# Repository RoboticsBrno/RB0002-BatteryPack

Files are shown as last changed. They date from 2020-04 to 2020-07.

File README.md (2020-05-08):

# RB0002-BatteryPack

Universal 2 cells Li-Ion battery pack with separate USB charger PCB for robot
power supplying.

This battery pack is designed for continuous 8.4 V / 15 A.

View this project on [CADLAB.io](https://cadlab.io/project/22740/).

License: [CC BY-SA 4.0](https://creativecommons.org/licenses/by-sa/4.0/?)

## Repository Structure

- `batteryPack` contains the main schematics and board drawing
- `doc` contains CubeMX pinout of the MCU, resistor calculation spreadsheet,
  etc.
- `footprints` contains the board-specific footprints
- `symbols` contains the board-specific symbols
- `tools` contains few scripts for automatization

## Building

Simply call `make` in the top-top level directory. The `build` directory will
them contain:

- split boards for the charger and the battery pack
- zipped gerbers for the boards you can directly use for manufacturing

Makefile uses [KiKit](https://github.com/yaqwsx/KiKit), therefore, it has to be
available on your system.

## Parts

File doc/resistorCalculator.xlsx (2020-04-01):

Resistor | Value |  | VCC | 3.30 V
R1 | 10000
R2 | 2400
R3 | 0
Scenario | Virtual resistor | Output Voltage | Divider Current
High impendance |  | 0.64 V | 0.3 mA
Low | 0 | 0.00 V | 0.3 mA
High | 0 | 3.30 V | 1.4 mA

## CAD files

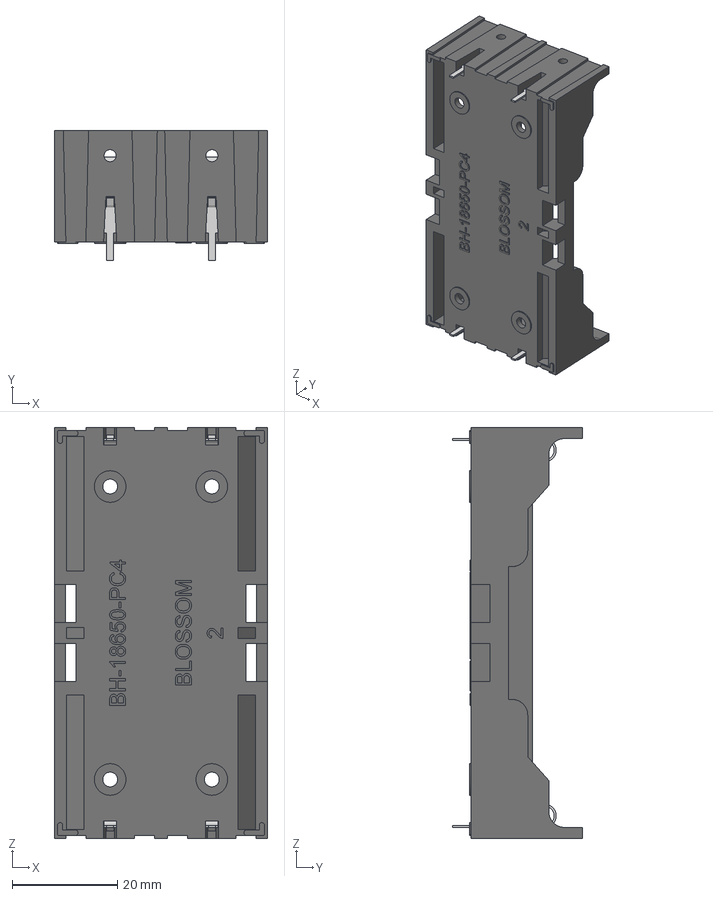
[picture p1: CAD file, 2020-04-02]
footprints/BAT_BK-18650-PC4.step
40.5 x 24.7 x 78.0 mm
Деталь2^Отсек акк умуляторный BC-18650-PC4
Деталь3^Отсек акк умуляторный BC-18650-PC4 x 4

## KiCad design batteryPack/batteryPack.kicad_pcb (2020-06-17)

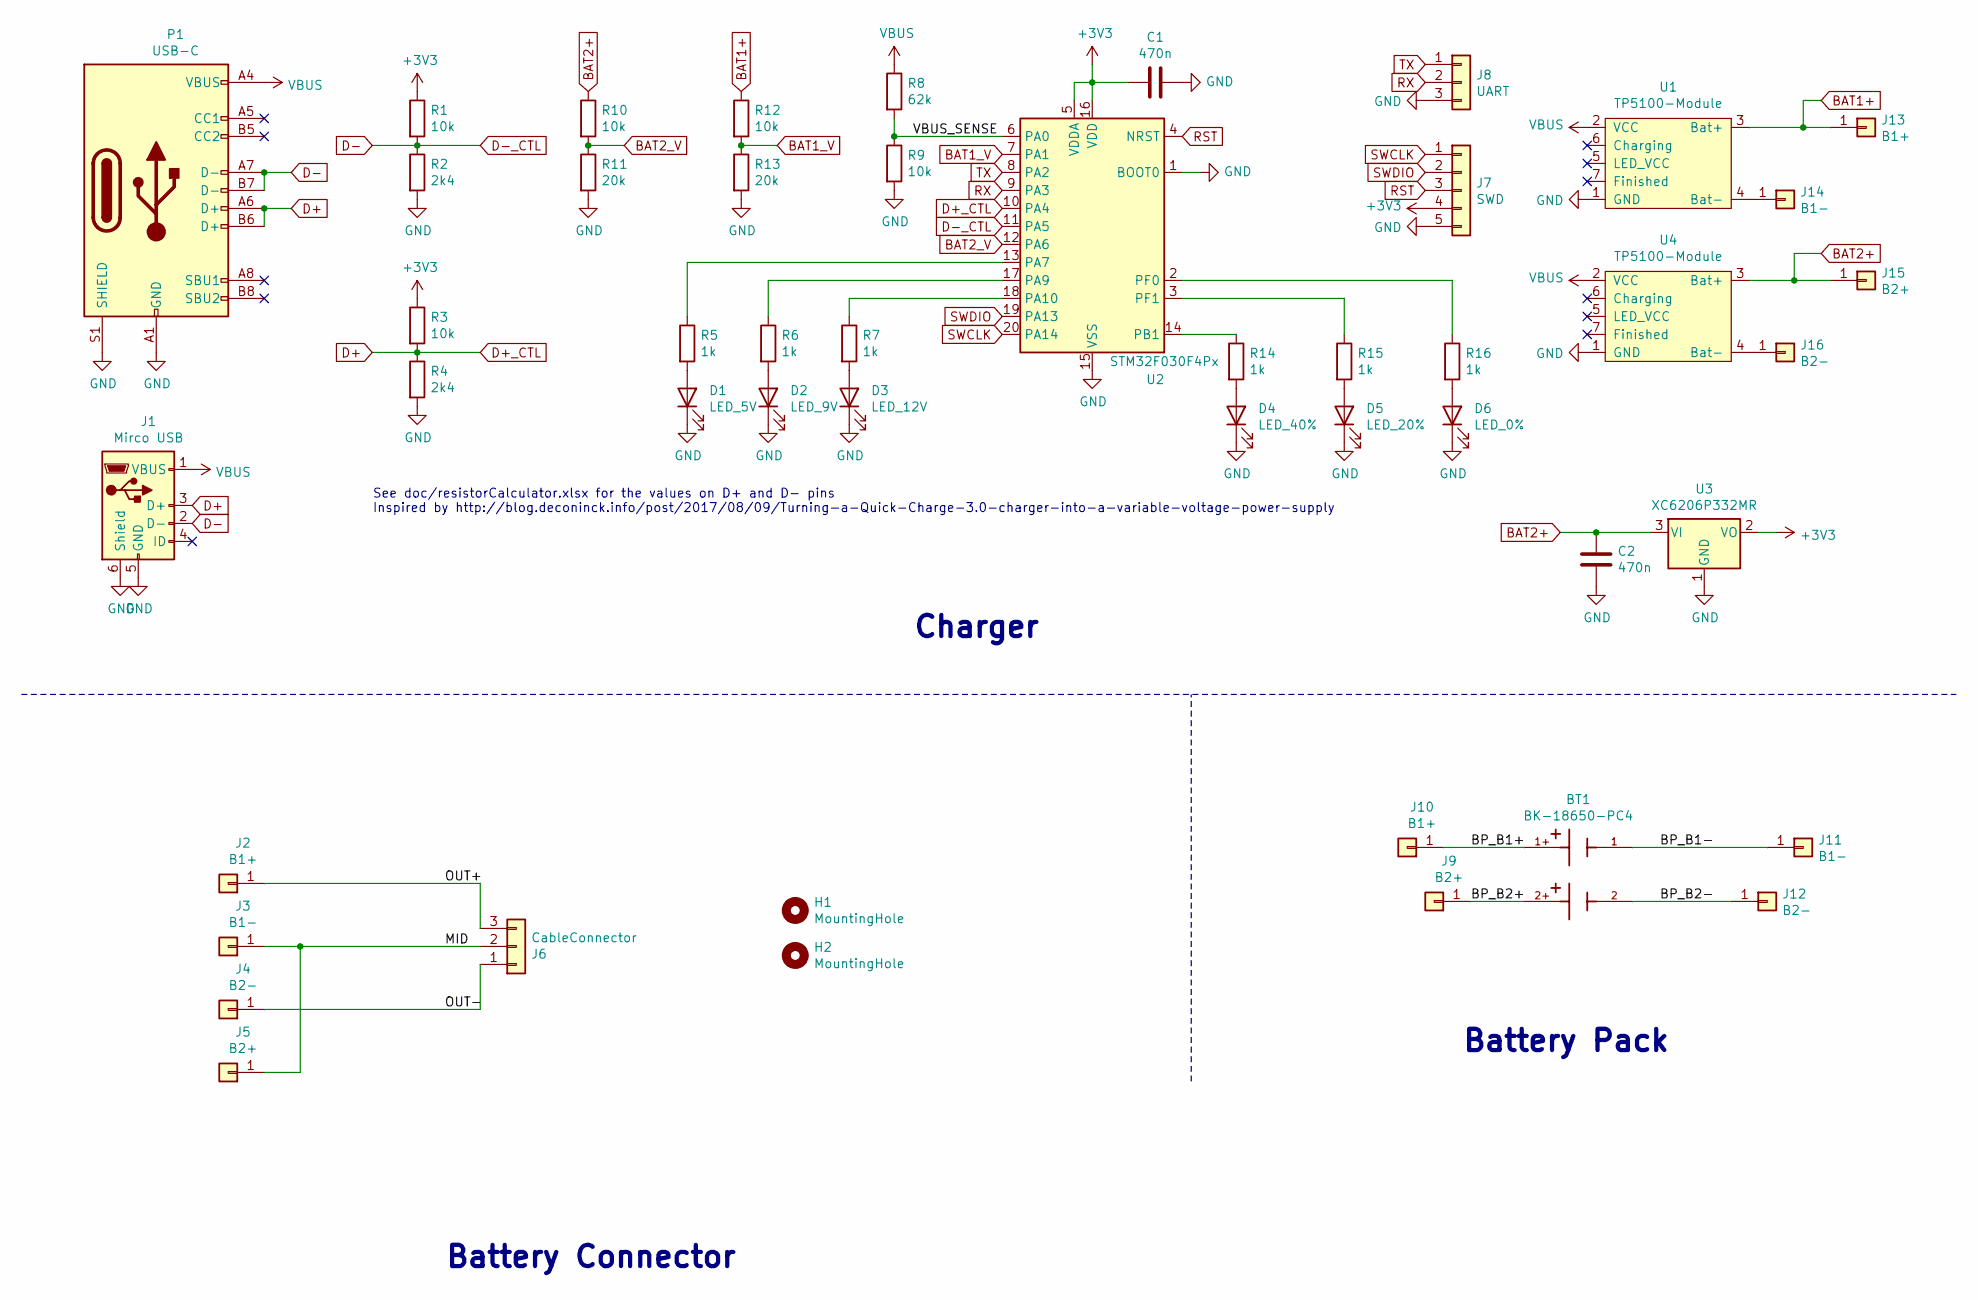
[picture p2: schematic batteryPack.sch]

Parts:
BT1: BK-18650-PC4; BAT_BK-18650-PC4
C1, C2: 470n; C_0603_1608Metric_Pad1.05x0.95mm_HandSolder
D1: LED_5V; LED_0603_1608Metric_Pad1.05x0.95mm_HandSolder
D2: LED_9V; LED_0603_1608Metric_Pad1.05x0.95mm_HandSolder
D3: LED_12V; LED_0603_1608Metric_Pad1.05x0.95mm_HandSolder
D4: LED_40%; LED_0603_1608Metric_Pad1.05x0.95mm_HandSolder
D5: LED_20%; LED_0603_1608Metric_Pad1.05x0.95mm_HandSolder
D6: LED_0%; LED_0603_1608Metric_Pad1.05x0.95mm_HandSolder
H1, H2: MountingHole; MountingHole_3.2mm_M3
J1: Mirco USB; USB_Micro-B_Wuerth_629105150521_CircularHoles
J2: B1+; 2mm_Banana-Vertical
J3: B1-; 2mm_Banana-Vertical
J4: B2-; 2mm_Banana-Vertical
J5: B2+; 2mm_Banana-Vertical
J6: CableConnector; Terminal_1x03_P5.08mm_Horizontal
J7: SWD; PinHeader_1x05_P2.54mm_Vertical
J8: UART; PinHeader_1x03_P2.54mm_Vertical
J9: B2+; 2mm_Banana-Socket
J10: B1+; 2mm_Banana-Socket
J11: B1-; 2mm_Banana-Socket
J12: B2-; 2mm_Banana-Socket
J13: B1+; 2mm_Banana-Plug
J14: B1-; 2mm_Banana-Plug
J15: B2+; 2mm_Banana-Plug
J16: B2-; 2mm_Banana-Plug
P1: USB-C; USB_C_Female-16Pin-HPJF
R1, R3, R9, R10, R12: 10k; R_0603_1608Metric_Pad1.05x0.95mm_HandSolder
R2, R4: 2k4; R_0603_1608Metric_Pad1.05x0.95mm_HandSolder
R5, R6, R7, R14, R15, R16: 1k; R_0603_1608Metric_Pad1.05x0.95mm_HandSolder
R8: 62k; R_0603_1608Metric_Pad1.05x0.95mm_HandSolder
R11, R13: 20k; R_0603_1608Metric_Pad1.05x0.95mm_HandSolder
U1, U4: TP5100-Module
U2: STM32F030F4Px; TSSOP-20_4.4x6.5mm_P0.65mm
U3: XC6206P332MR; SOT-23

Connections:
+3V3: C1.2, J7.4, R1.1, R3.1, U2.5 (VDDA), U2.16 (VDD), U3.2 (VO)
/BP_B1+: BT1.1+, J10.1
/BP_B1-: BT1.1 (1-), J11.1
/BP_B2+: BT1.2+, J9.1
/BP_B2-: BT1.2 (2-), J12.1
/MID: J3.1, J5.1, J6.2
/OUT+: J2.1, J6.3
/OUT-: J4.1, J6.1
/VBUS_SENSE: R8.2, R9.1, U2.6 (PA0)
BAT1+: J13.1, R12.1, U1.3 (Bat+)
BAT1_V: R12.2, R13.1, U2.7 (PA1)
BAT2+: C2.2, J15.1, R10.1, U3.3 (VI), U4.3 (Bat+)
BAT2_V: R10.2, R11.1, U2.12 (PA6)
D+: J1.3 (D+), P1.A6 (D+), P1.B6 (D+), R3.2, R4.1, U2.10 (PA4)
D-: J1.2 (D-), P1.A7 (D-), P1.B7 (D-), R1.2, R2.1, U2.11 (PA5)
GND: C1.1, C2.1, D1.1 (K), D2.1 (K), D3.1 (K), D4.1 (K), D5.1 (K), D6.1 (K), J1.5 (GND), J1.6 (Shield), J7.5, J8.3, P1.A1 (GND), P1.A12 (GND), P1.B1 (GND), P1.B12 (GND), P1.S1 (SHIELD), R2.2, R4.2, R9.2, R11.2, R13.2, U1.1 (GND), U2.1 (BOOT0), U2.15 (VSS), U3.1 (GND), U4.1 (GND)
unnamed: D1.2 (A), R5.2
unnamed: D2.2 (A), R6.2
unnamed: D3.2 (A), R7.2
unnamed: D4.2 (A), R14.2
unnamed: D5.2 (A), R15.2
unnamed: D6.2 (A), R16.2
unnamed: J14.1, U1.4 (Bat-)
unnamed: J16.1, U4.4 (Bat-)
unnamed: R5.1, U2.13 (PA7)
unnamed: R6.1, U2.17 (PA9)
unnamed: R7.1, U2.18 (PA10)
unnamed: R14.1, U2.14 (PB1)
unnamed: R15.1, U2.3 (PF1)
unnamed: R16.1, U2.2 (PF0)
RST: J7.3, U2.4 (NRST)
RX: J8.2, U2.9 (PA3)
SWCLK: J7.1, U2.20 (PA14)
SWDIO: J7.2, U2.19 (PA13)
TX: J8.1, U2.8 (PA2)
VBUS: J1.1 (VBUS), P1.A4 (VBUS), P1.A9 (VBUS), P1.B4 (VBUS), P1.B9 (VBUS), R8.1, U1.2 (VCC), U4.2 (VCC)

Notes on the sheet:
Battery Pack
Charger
Battery Connector
See doc/resistorCalculator.xlsx for the values on D+ and D- pins Inspired by http://blog.deconinck.info/post/2017/08/09/Turning-a-Quick-Charge-3.0-charger-into-a-variable-voltage-power-supply

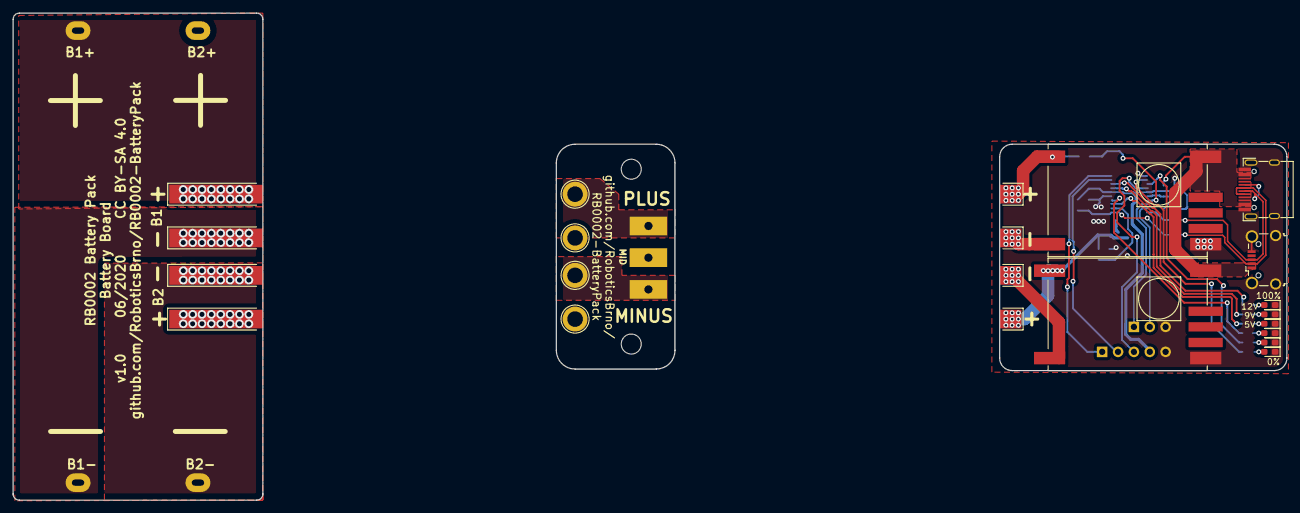
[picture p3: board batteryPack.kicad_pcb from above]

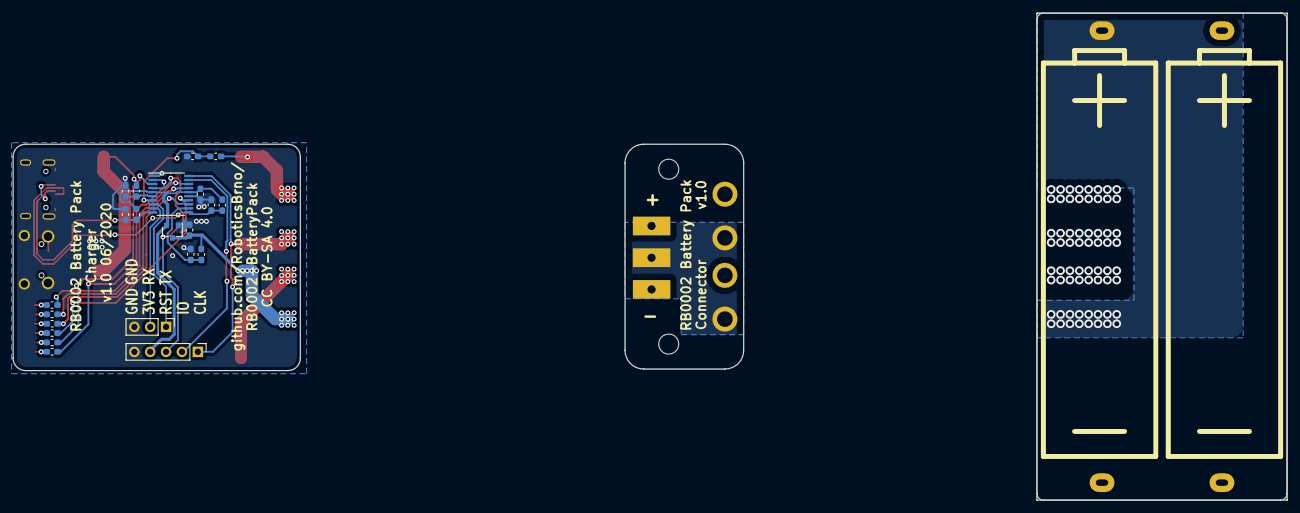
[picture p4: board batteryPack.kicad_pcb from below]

Board: 2 copper layers, 204.0 x 78.0 mm, 48 parts (23 on the bottom side), 36 nets.

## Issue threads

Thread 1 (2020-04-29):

Add terminal block

cednik, 2020-04-29:
Change Connector board output terminals pitch to 5.08 mm, because of terminal block.

yaqwsx, 2020-05-05:
Changed in c155f3b482ff61e23f10e315877f0c11cceca71f

Closed 2020-05-05.

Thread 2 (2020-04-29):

Swap copper layers on Battery Board

cednik, 2020-04-29:
Swap copper layers on Battery Board, because of only one signal should go through vias, instead of three.

yaqwsx, 2020-05-05:
Changed in 654a4b0aeea430922793bae846b96a86840165b2

Closed 2020-05-05.

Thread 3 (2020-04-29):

Add measuring of battery voltage

JarekParal, 2020-04-29:

yaqwsx, 2020-05-06:
Implemented in 16e597c14b0a554ac6515b566eaac2d2ae36eb89

Please, review it @JarekParal @cednik before closing.

JarekParal, 2020-05-08:
I checked and everything seems fine.

Closing.

Closed 2020-05-08.

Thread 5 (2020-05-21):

Narrow down battery holder footprint

yaqwsx, 2020-05-21:
The pads are 1-2mm further away than it would be suitable.

yaqwsx, 2020-06-17:
Fixed in 6bc1cba907001277c97434f54d5b472d14ae1b37

Closed 2020-06-17.

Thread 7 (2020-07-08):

Notebook chargers do not work with the charger

yaqwsx, 2020-07-08:
It is probably caused by not connecting CC1/CC2 pins on USB-C

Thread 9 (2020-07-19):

The charger should show summary capacity info

yaqwsx, 2020-07-19:
Currently, the implementation can measure the voltage of both cells, however, it shows only the voltage of one of them as showing both is confusing for the users. We should sum both voltages of the cells and use it as the input for the LED bar.

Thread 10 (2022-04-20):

Wrong KiKit panelize syntax in makefile

bsaid, 2022-04-20:
```
/RB0002-BatteryPack$ make
kikit panelize extractboard -s 175 50 70 40 batteryPack/batteryPack.kicad_pcb build/charger.kicad_pcb
Usage: kikit panelize [OPTIONS] INPUT OUTPUT
Try 'kikit panelize --help' for help.

Error: Got unexpected extra arguments (70 40 batteryPack/batteryPack.kicad_pcb build/charger.kicad_pcb)
make: *** [Makefile:12: build/charger.kicad_pcb] Error 2
```

Platform: Xubuntu 20.04, Python 3.8.10, KiKit version 1.0.5

Maybe the syntax changed with the new version of KiKit?
This project is mentioned as an example project inside KiKit README, so this is why I care about this issue.

yaqwsx, 2022-04-20:
Yes, this project uses KiKit v0.4, however, there were major breaking changes in the v1.0 release.

Where did you find the mention of a Battery pack being an example? All the notes about it should be gone.

bsaid, 2022-04-20:
[https://github.com/yaqwsx/KiKit/blob/master/README.md](https://github.com/yaqwsx/KiKit/blob/master/README.md?plain=1) line 65

yaqwsx, 2022-04-20:
Thanks, I removed the notes. I think you might want to start with: https://github.com/yaqwsx/KiKit/blob/master/doc/examples.md

bsaid, 2022-04-20:
I started there, but I was looking for how to make a panel from several different PCBs. Can you add this case to your examples?

yaqwsx, 2022-04-20:
That's a duplicate of:
- https://github.com/yaqwsx/KiKit/issues/283
- https://github.com/yaqwsx/KiKit/discussions/327

Currently, this is somewhere on my Todo list, but low in priority.

Closed 2022-04-20.

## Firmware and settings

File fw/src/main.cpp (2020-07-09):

#include <stm32f0xx_hal.h>
#include "statusBar.hpp"
#include "adc.hpp"
#include "qc.hpp"

void ErrorHandler() {
    Dbg::print( "A fatal error occured" );
    while( true );
}

void SystemClock_Config(void) {
    RCC_OscInitTypeDef RCC_OscInitStruct = {0};
    RCC_ClkInitTypeDef RCC_ClkInitStruct = {0};
    RCC_PeriphCLKInitTypeDef PeriphClkInit = {0};

    /** Initializes the CPU, AHB and APB busses clocks
     */
    RCC_OscInitStruct.OscillatorType = RCC_OSCILLATORTYPE_HSI|RCC_OSCILLATORTYPE_HSI14;
    RCC_OscInitStruct.HSIState = RCC_HSI_ON;
    RCC_OscInitStruct.HSI14State = RCC_HSI14_ON;
    RCC_OscInitStruct.HSICalibrationValue = RCC_HSICALIBRATION_DEFAULT;
    RCC_OscInitStruct.HSI14CalibrationValue = 16;
    RCC_OscInitStruct.PLL.PLLState = RCC_PLL_NONE;
    if (HAL_RCC_OscConfig(&RCC_OscInitStruct) != HAL_OK)
        ErrorHandler();

    /** Initializes the CPU, AHB and APB busses clocks
     */
    RCC_ClkInitStruct.ClockType = RCC_CLOCKTYPE_HCLK|RCC_CLOCKTYPE_SYSCLK
                                |RCC_CLOCKTYPE_PCLK1;
    RCC_ClkInitStruct.SYSCLKSource = RCC_SYSCLKSOURCE_HSI;
    RCC_ClkInitStruct.AHBCLKDivider = RCC_SYSCLK_DIV1;
    RCC_ClkInitStruct.APB1CLKDivider = RCC_HCLK_DIV1;

    if (HAL_RCC_ClockConfig(&RCC_ClkInitStruct, FLASH_LATENCY_0) != HAL_OK)
        ErrorHandler();

    PeriphClkInit.PeriphClockSelection = RCC_PERIPHCLK_USART1;
    PeriphClkInit.Usart1ClockSelection = RCC_USART1CLKSOURCE_PCLK1;
    if (HAL_RCCEx_PeriphCLKConfig(&PeriphClkInit) != HAL_OK)
        ErrorHandler();
}

int main() {
    HAL_Init();
    SystemClock_Config();

    __HAL_RCC_GPIOF_CLK_ENABLE();
    __HAL_RCC_GPIOA_CLK_ENABLE();
    __HAL_RCC_GPIOB_CLK_ENABLE();
    __HAL_RCC_USART1_CLK_ENABLE();
    __HAL_RCC_ADC1_CLK_ENABLE();


    StatusBar bar;
    AnalogPhy analogPhy;
    Qc2Control qcControl( { GPIOA, GPIO_PIN_4 }, { GPIOA, GPIO_PIN_5 } );

    Percents percentAnim( bar, 0 );
    BusVoltage voltageAnim( bar, 0 );

    SlidingAverage< float, 4 > busSlidingAvg;

    const int MODE_PERIOD = 5000;

    while ( true ) {
        auto tick = HAL_GetTick();
        float busVoltage = analogPhy.busVoltage();
        busSlidingAvg.push( busVoltage );
        busVoltage = busSlidingAvg.avg();
        qcControl.run( busVoltage, tick );
        if ( tick % MODE_PERIOD < MODE_PERIOD / 2 || busVoltage < 3 ) {
            percentAnim.set( batteryPercent( analogPhy.batt1Voltage() ) );
            percentAnim( tick );
        }
        else {
            voltageAnim.set( busVoltage );
            voltageAnim( tick );
        }
    }
}

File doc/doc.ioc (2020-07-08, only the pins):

Mcu.UserName=STM32F030F4Px
PA0.Signal=ADC_IN0
PA1.Signal=ADC_IN1
PA10.Signal=GPIO_Output
PA13.Signal=SYS_SWDIO
PA14.Signal=SYS_SWCLK
PA2.Signal=USART1_TX
PA3.Signal=USART1_RX
PA6.Signal=ADC_IN6
PA7.Signal=GPIO_Output
PA9.Signal=GPIO_Output
PB1.Signal=GPIO_Output
PF0-OSC_IN.Signal=GPIO_Output
PF1-OSC_OUT.Signal=GPIO_Output

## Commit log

2020-03-31 Prepare initial structure
    [batteryPack.kicad_pcb, batteryPack.sch]
2020-03-31 README.md: Add info about battery pack and USB charger
2020-04-01 Add documentation
    [resistorCalculator.xlsx]
2020-04-01 Finish first draft of the schematics
    [batteryPack.kicad_pcb, batteryPack.sch]
2020-04-01 Sketch out initial component layout
    [batteryPack.kicad_pcb, batteryPack.sch]
2020-04-01 Route battery and the connector
    [batteryPack.kicad_pcb, batteryPack.sch]
2020-04-01 Route the charger
    [batteryPack.kicad_pcb, batteryPack.sch]
2020-04-01 Make the labels nice
    [batteryPack.kicad_pcb]
2020-04-01 Update Makefile for all three subboards
    [batteryPack.kicad_pcb]
2020-04-02 Add battery holder 3D model
    [BAT_BK-18650-PC4.step]
2020-04-02 Fine tune the board based on the feedback
    [batteryPack.kicad_pcb, batteryPack.sch]
2020-04-07 Migrate Makefile to KiKit
    [batteryPack.kicad_pcb]
2020-04-21 Fine tune TP5100 footprint
2020-04-26 Fix erroreous charger extraction
2020-04-29 Swap layers on battery board
    [batteryPack.kicad_pcb]
2020-04-29 Add tenons and handle to the battery
    [batteryPack.kicad_pcb]
2020-04-29 Change connector to screw terminal
    [batteryPack.kicad_pcb, batteryPack.sch]
2020-05-05 Tune pull handle and battery panel
    [batteryPack.kicad_pcb]
2020-05-06 Add battery voltage signalization
    [batteryPack.kicad_pcb, batteryPack.sch]
2020-05-08 Add silkscreen text + LICENSE
    - add version info text to Charger board
    - add +/- text for Charger and Connector board
    - add license Creative Commons BY-SA 4.0
    [batteryPack.kicad_pcb]
2020-06-17 Remove tenons from the battery
    [batteryPack.kicad_pcb]
2020-06-17 Make ptich of battery holder smaller
    [batteryPack.kicad_pcb]
2020-06-17 Mark the battery polarity on the other side
    [batteryPack.kicad_pcb]
2020-06-17 Make room for mouse bites
    [batteryPack.kicad_pcb]
2020-06-17 Bump version on silkscreen to 1.0
    [batteryPack.kicad_pcb]
2020-06-17 Modify Makefile panelization for manufactoring
    - replace mousebits with V-cuts on battery board (after removing tenons it is posible to use V-cuts)
    - replace V-cut with mousebites on charge board due to PCBA
2020-07-09 Add filtering of bus voltage

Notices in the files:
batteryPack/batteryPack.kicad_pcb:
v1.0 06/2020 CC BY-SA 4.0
